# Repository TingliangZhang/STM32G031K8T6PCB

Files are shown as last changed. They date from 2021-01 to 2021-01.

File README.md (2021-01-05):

# STM32G031K8T6PCB
STM32G031K8T6 未来交互牌 开发板 PCB设计 KiCAD

参考设计：MB1455 [**NUCLEO-G031K8**](https://www.st.com/en/evaluation-tools/nucleo-g031k8.html) 原理图

## MCU

[STM32G031K8](https://www.st.com/en/microcontrollers-microprocessors/stm32g031k8.html)

## 晶振

晶振设计参考AN2867
$$
\mathrm{C}_{\mathrm{L}}=\frac{\mathrm{C}_{\mathrm{L} 1} \times \mathrm{C}_{\mathrm{L} 2}}{\mathrm{C}_{\mathrm{L} 1}+\mathrm{C}_{\mathrm{L} 2}}+\mathrm{C}_{\mathrm{S}}
$$
[ TST(台湾嘉硕) 32M ±10ppm 12pF ](https://item.szlcsc.com/510342.html)

求得负载电容为20pF

## 烧写器

[STLINK-V3MINI](https://www.st.com/en/development-tools/stlink-v3mini.html)

开发板上接口为STDC14 2x7 1.27mm排母

[ST-LINK/V2 ](https://www.st.com/en/development-tools/st-link-v2.html)

Target connection(SWD) 

20-pin JTAG 2x10 2.54mm 排针

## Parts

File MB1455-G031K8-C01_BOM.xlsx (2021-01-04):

 |  |  | Bill of materials
 |  |  | Board reference: | MB1455
 |  |  | Variant: | G031K8
 |  |  | PCB revision: | C
 |  |  | Assembly revision: | 01
 |  |  | Date: | 04-Mar-19
Designator | Description | Package | Manufacturer | Manufacturer_Part_Number | Fitted | Quantity
B1 | Subminiature Side Actuated Tact Switch for SMT - KSS series - 2.0 Newtons - Gull wing, SPST |  | C&K | KSS221GLFS | Fitted | 1
C1, C2, C4, C5, C6, C7, C11, C13, C14, C17, C18, C21, C25 | Capacitor, MLCC, 100nF, 16V, X7R, 10%, 0402, T=0,5mm | C0402 | YAGEO | CC0402KRX7R7BB104 | Fitted | 13
C8 | Capacitor, MLCC, 10nF, 16V, X7R, 10%, 0402, T=0.5mm | C0402 | YAGEO | CC0402KRX7R7BB103 | Fitted | 1
C9, C10, C12, C19, C20 | Capacitor, MLCC, 1uF, 6V3, X5R, 10%, 0402, T=0,5mm | C0402 | MURATA | GRM155R61E105KA12 | Fitted | 5
C15, C16 | Capacitor, MLCC, 5.6pF, 50V, NPO, +/- 0.1pF, 0402, T=0,5mm | C0402 | YAGEO | CC0402BRNPO9BN5R6 | Fitted | 2
C22, C23 | Capacitor, MLCC, 10pF, 50V, NPO, 5%, 0402, T=0,5mm | C0402 | YAGEO | CC0402JRNPO9BN100 | Fitted | 2
C24, C27 | Capacitor, MLCC, 10uF, 25V, X5R, 10%, 0805, T=0,85mm | C0805 | YAGEO | CC0805KRX5R8BB106 | Fitted | 2
C26 | Capacitor, MLCC, 4.7uF, 6V3, X5R, 20%, 0402, T=0,5mm | C0402 | MURATA | GRM155R60J475ME87 | Fitted | 1
CN1 | USB-MICRO-B, 0.65mm, RA, SMT, Bottom Mount, |  | MOLEX | 1050170001 | Fitted | 1
CN3, CN4 | Pin header, 15x1, 2,54mm, VR, TH, Height 6mm/6mm |  | LYCONN | 313115S161145 | Fitted | 2
D1, D2, D3, D4 | BAT60JFILM |  | STMICROELECTRONICS | BAT60JFILM | Fitted | 4
D5 | LOW DROP POWER SCHOTTKY RECTIFIER 1A 30V VF=0.3V | DIO_SMA_1A_2K | STMICROELECTRONICS | STPS1L30A | Fitted | 1
HW1 | SHUNT, 2.54mm, height 6.10mm, BLACK |  | SAMTEC | SNT-100-BK-G | Fitted | 1
HW2 | SHUNT 1.27mm BLACK |  | W & P Products | 266-101-10-00 | Fitted | 1
HW3 | Sticker to mention board reference + serial number |  | n/a | n/a | Fitted | 1
HW4 | Sticker to mention board CPN code |  | n/a | n/a | Fitted | 1
HW5 | PCB, xxxx for PCB number, Y for PCB revision |  | n/a | n/a | Fitted | 1
JP1 | Header, 2x1, 1,27mm, Right Angled, Single Row, Height 3.05mm/1.27mm |  | W & P Products | 707-2-02-2-20-00 | Fitted | 1
LD1 | LED Bicolor |  | AVAGO TECHNOLOGIES | HSMF-A201-A00J1 | Fitted | 1
LD2, LD4 | LED, Red, 0603 | LED 0603 | EVERLIGHT | 19-217/R6C-AL1M2VY/3T | Fitted | 2
LD3 | LED, Green, 0603 | LED 0603 | EVERLIGHT | 19-213SYGC/S530-E2/TR8 | Fitted | 1
Q1, Q2 | NPN Bipolar Transistor | SOT23 | ON SEMICONDUCTOR | BSR14 | Fitted | 2
R1 | Resistor,1K5,0402,1%,1/16W | R0402 | YAGEO | RC0402FR-071K5L | Fitted | 1
R2, R14, R21 | Resistor,100K,0402,1%,1/16W | R0402 | YAGEO | RC0402FR-07100KL | Fitted | 3
R3, R23 | Resistor,1K,0402,1%,1/16W | R0402 | YAGEO | RC0402FR-071KL | Fitted | 2
R4 | Resistor,36K,0402,1%,1/16W | R0402 | YAGEO | RC0402FR-0736KL | Fitted | 1
R5, R13, R15, R16 | Resistor,10K,0402,1%,1/16W | R0402 | YAGEO | RC0402FR-0710KL | Fitted | 4
R6, R7, R19 | Resistor,100R,0402,1%,1/16W | R0402 | YAGEO | RC0402FR-07100RL | Fitted | 3
R8 | Resistor,2K7,0402,1%,1/16W | R0402 | YAGEO | RC0402FR-072K7L | Fitted | 1
R9, R10, R11 | Resistor,4K7,0402,1%,1/16W | R0402 | YAGEO | RC0402FR-074K7L | Fitted | 3
R17, R18 | Resistor,330R,0402,1%,1/16W | R0402 | YAGEO | RC0402FR-07330RL | Fitted | 2
R20 | Resistor,510R,0402,1%,1/16W | R0402 | YAGEO | RC0402FR-07510RL | Fitted | 1
R22 | Resistor,47K,0402,1%,1/16W | R0402 | YAGEO | RC0402FR-0747KL | Fitted | 1
SB3, SB4, SB5, SB8, SB9, SB10, SB11, SB13 | Solder Bridge ON | SB0603 | YAGEO | RC0603JR-070RL | Fitted | 8
U1 | 200 mA low quiescent current very low noise LDO | SOT23-5L | STMICROELECTRONICS | LDK120M33R | Fitted | 1
U2 | Mainstream Arm Cortex-M0+ MCU with 64 Kbytes of of Flash memory memory, 8 Kbytes RAM, 64 MHz CPU, 2x USART, timers, ADC, comm. I/F, 1.65-3.6V | LQFP32 | STMICROELECTRONICS | STM32G031K8T6U | Fitted | 1
U3 | Low quiescent current and low noise voltage regulators | DFN6 3x3mm | STMICROELECTRONICS | LD39050PU33R | Fitted | 1
U4 | ESD protection 6V1 |  | STMICROELECTRONICS | ESDALC6V1-1U2 | Fitted | 1
U5 | Enhanced single channel power switches with active low enable pin |  | STMICROELECTRONICS | STMPS2141STR | Fitted | 1
U6 | USB OTG FS ESD protection |  | STMICROELECTRONICS | USBLC6-2P6 | Fitted | 1
U7 | Medium-density performance line ARM-based 32-bit MCU with 128KB Flash |  | STMICROELECTRONICS | STM32F103CBT6 | Fitted | 1
U8 | IC REG LDO 5V 0.8A SOT223 | SOT-223 | STMICROELECTRONICS | LD1117S50TR | Fitted | 1
X1 | Crystal 32.768kHz, 6pF, +-20ppm, 50Kohms max, SMD |  | NDK | NX3215SA 32.768KHz EXS00A-MU00525 | Fitted | 1
X2 | Crystal 8MHz, 8pF, +-20ppm, 500ohms max, SMD |  | NDK | NX3225GD 8MHz EXS00A-CG04874 | Fitted | 1
C3 | Capacitor, MLCC, 20pF, 50V, NPO, 5%, 0402, T=0,5mm | C0402 | YAGEO | CC0402JRNPO9BN200 | Not Fitted | 0
CN2 | Header 5 pads for ST-LINK prog. Not fitted |  | n/a | n/a | Not Fitted | 0
R12 | Resistor,10K,0402,1%,1/16W | R0402 | YAGEO | RC0402FR-0710KL | Not Fitted | 0
SB1, SB2, SB6, SB7, SB12 | Solder Bridge OFF | SB0603 | YAGEO | RC0603JR-070RL | Not Fitted | 0

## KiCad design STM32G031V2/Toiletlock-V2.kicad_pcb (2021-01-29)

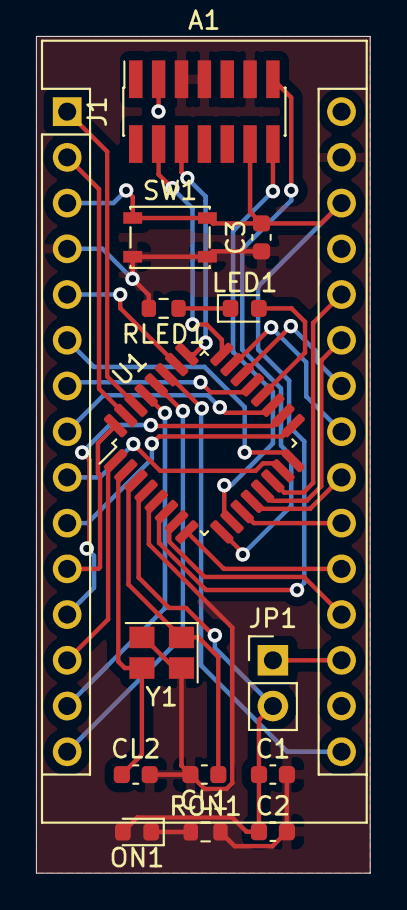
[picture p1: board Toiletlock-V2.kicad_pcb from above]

Board: 2 copper layers, 18.5 x 46.5 mm, 15 parts (0 on the bottom side), 35 nets.

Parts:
A1: Arduino_Nano_v2.x; Arduino_Nano
C1: 4.7uF; C_0603_1608Metric
C2, C3: 100nF; C_0603_1608Metric
CL1, CL2: 20pF; C_0603_1608Metric
J1: Conn_ST_STDC14; PinSocket_2x07_P1.27mm_Vertical_SMD
JP1: Jumper; PinHeader_1x02_P2.54mm_Vertical
LED1: LED; LED_0603_1608Metric
ON1: LED; LED_0603_1608Metric
RLED1: 1k; R_0603_1608Metric
RON1: 1k; R_0603_1608Metric
SW1: SW_Push; SW_SPST_PTS810
U1: STM32G031K8T3; LQFP-32_7x7mm_P0.8mm
Y1: Crystal_GND24; Crystal_SMD_3225-4Pin_3.2x2.5mm

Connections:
+3V3: A1.17, C1.1, C2.1, J1.3, JP1.2, ON1.2, U1.4
/NRST: A1.3, A1.28, C3.2, J1.12, SW1.1, U1.6
/PA0: A1.19, U1.7
/PA1: A1.20, U1.8
/PA4: A1.21, U1.11
/PA5: A1.22, U1.12
/PA6: A1.25, U1.13
/PA7: A1.26, U1.14
/PA8: A1.12, U1.18
/PA9: A1.8, U1.19
/PA10: A1.7, U1.21
/PA11: A1.24, U1.22
/PA12: A1.23, U1.23
/PA15: A1.5, U1.26
/PB0: A1.9, U1.15
/PB1: A1.6, U1.16
/PB2: A1.10, U1.17
/PB3: A1.16, U1.27
/PB4: A1.15, U1.28
/PB5: A1.14, U1.29
/PB6: A1.1, U1.30
/PB7: A1.2, U1.31
/PB8: A1.11, U1.32
/PB9: A1.13, U1.1
/PC6: LED1.2, U1.20
/SWCLK: J1.6, U1.25
/SWDIO: J1.4, U1.24
GND: A1.4, A1.29, C1.2, C2.2, C3.1, CL1.2, CL2.2, J1.5, J1.7, J1.11, RLED1.2, RON1.2, SW1.2, U1.5, Y1.2, Y1.4
unnamed: A1.18, JP1.1
unnamed: CL1.1, U1.3, Y1.1
unnamed: CL2.1, U1.2, Y1.3
unnamed: LED1.1, RLED1.1
unnamed: ON1.1, RON1.1
T_VCP_RX: J1.14, U1.10
T_VCP_TX: J1.13, U1.9

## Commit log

2021-01-04 STM32G031K8T6PCB ini
    [STM32G031.kicad_pcb, STM32G031.sch]
2021-01-04 Simple system
    [STM32G031.kicad_pcb, STM32G031.sch]
2021-01-07 Fab V1
    [STM32G031.kicad_pcb]
2021-01-29 Import From toilet lock V2
    [Toiletlock-V2.kicad_pcb, Toiletlock-V2.sch]
2021-01-29 add led on
    [Toiletlock-V2.kicad_pcb, Toiletlock-V2.sch]
2021-01-29 Finsh V2 Dev Board
    [Toiletlock-V2.kicad_pcb, Toiletlock-V2.sch]
